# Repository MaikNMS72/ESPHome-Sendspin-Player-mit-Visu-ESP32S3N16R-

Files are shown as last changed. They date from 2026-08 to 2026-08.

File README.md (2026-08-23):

# Sendspin Gartenhaus ESPHome Player

ESPHome-Konfiguration fuer einen ESP32-S3 Player mit Sendspin,
I2S-Audio, ILI9341-Display, WS2812 Sound-to-Light und lokaler Bedienung ueber
Drehencoder und Tasten.

Der aktuelle stabile Stand ist:

`versions/sendspin-media-gartenhaus_2026-08-23_subpixel-vu-default150-nodebug.yaml`

Die aktive Datei zum Flashen ist:

`sendspin_gartenhaus_player.yaml`

## Funktionen

- Sendspin Medienplayer fuer Home Assistant
- lokaler `speaker_source` Player fuer Audioausgabe ueber I2S-Verstaerker
- Album-Art auf dem TFT-Display
- Titel, Interpret und Album als Laufschrift
- Fortschrittsbalken mit Laufzeit und Gesamtdauer
- Power-Schalter fuer Home Assistant und lokale OK-Langdruck-Bedienung
- WS2812 Sound-to-Light als analog wirkender VU-Ring
- Helligkeit und Empfindlichkeit in Home Assistant einstellbar
- Standard-Empfindlichkeit: 150%
- oberer Empfindlichkeitsbereich wird intern sanfter skaliert, damit 250% nicht sofort voll uebersteuert
- Rotary Encoder fuer Lautstaerke
- lokale Tasten fuer Tracksteuerung

## Hardware

- Board: ESP32-S3 DevKitC-1
- Flash: 16 MB
- PSRAM: Octal, 80 MHz
- Audio: zwei externe I2S-Mono-Verstaerker fuer Stereo
- Display: ILI9341 ueber SPI
- LED: WS2812 an GPIO14
- LED-Anzahl in ESPHome: 16
- Aufbau: zwei 16er-LED-Ringe parallel, deshalb wird nur ein 16er-Ring angesteuert

Details stehen in [docs/PINOUT.md](docs/PINOUT.md).
Die Bauteilliste steht in [docs/BOM.md](docs/BOM.md).

## Audio-Verstaerker

Fuer Stereo werden zwei I2S-Mono-Verstaerker verwendet. Beide Module bekommen
die I2S-Signale parallel vom ESP32-S3:

- BCLK: `GPIO7`
- LRCLK / WS: `GPIO5`
- DIN: `GPIO6`

Am linken Modul wird die L/R- beziehungsweise Channel-Select-Bruecke auf links
gesetzt, am rechten Modul auf rechts. Jeder Verstaerker treibt genau einen
Lautsprecher.

## Bilder und Demo

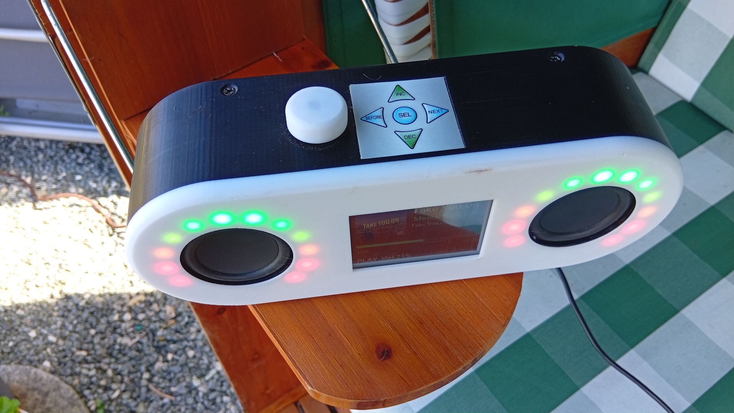
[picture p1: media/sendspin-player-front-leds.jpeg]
Sendspin Player Front mit LEDs


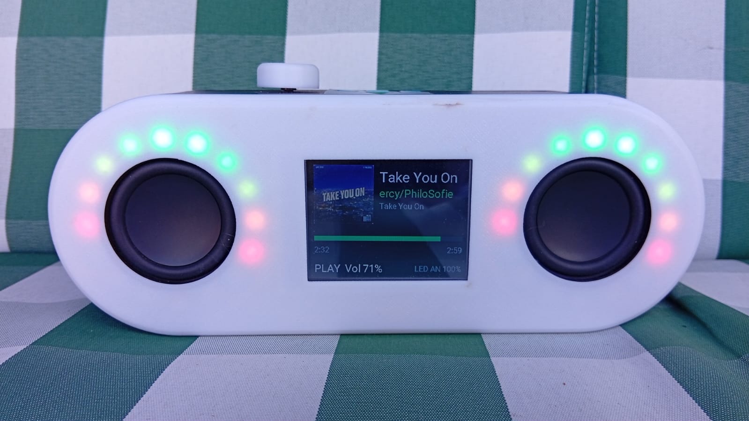
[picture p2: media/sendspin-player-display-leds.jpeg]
Sendspin Player Display und LED-Ringe


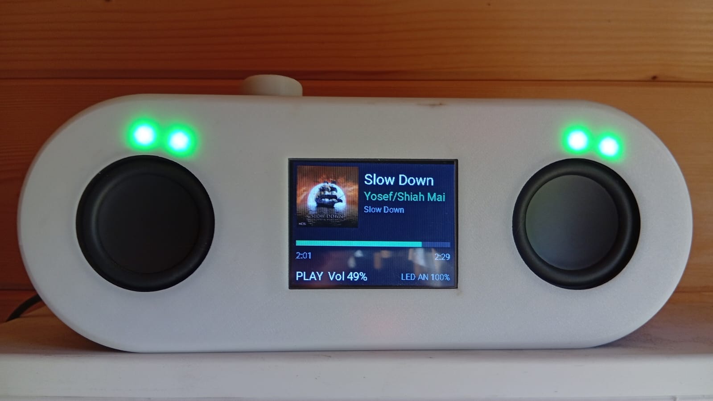
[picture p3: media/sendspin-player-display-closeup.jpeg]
Sendspin Player Display Nahaufnahme


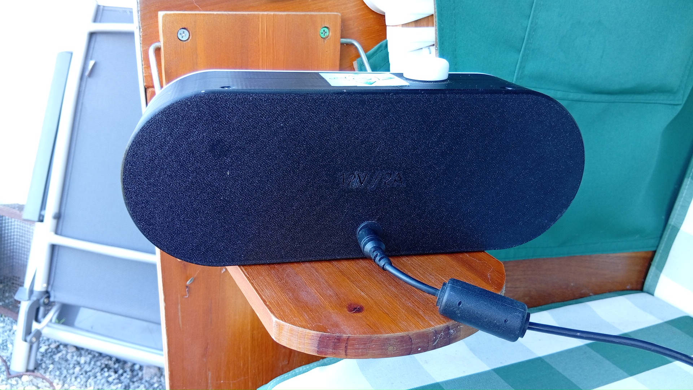
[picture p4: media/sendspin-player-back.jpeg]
Sendspin Player Rueckseite


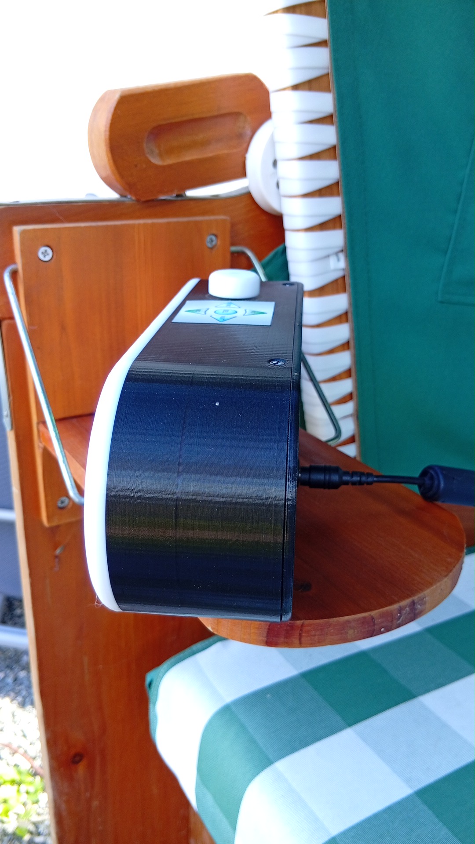
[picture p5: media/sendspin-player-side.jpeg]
Sendspin Player Seitenansicht


Video-Demo:
[YouTube: Sendspin Player Visualizer Demo](https://youtu.be/OSCCFwxxo4M)

Lokale Videodatei:
[sendspin-player-visualizer-demo.mp4](media/sendspin-player-visualizer-demo.mp4)

## 3D-Druckdaten

Die Gehaeusedaten liegen im Ordner [3d-print](3d-print/):

- `gehaeuse-esp32s3n16r8-lcd-encoder-button-body-fillet.3mf`
- `deckel-fillet001.3mf`
- `encoder-knopf-body-fillet.3mf`

Die Dateien sind im 3MF-Format abgelegt und fuer das Gehaeuse mit ESP32-S3,
LCD, Encoder und Tasten gedacht.

Vorschau:

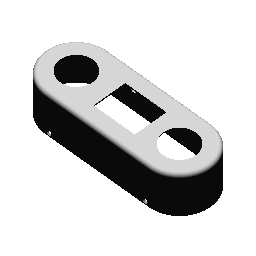
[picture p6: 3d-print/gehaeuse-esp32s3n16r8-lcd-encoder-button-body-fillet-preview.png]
Gehaeuse Vorschau

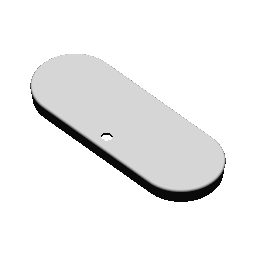
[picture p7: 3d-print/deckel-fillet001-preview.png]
Deckel Vorschau

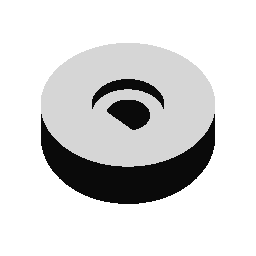
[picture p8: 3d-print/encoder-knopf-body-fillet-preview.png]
Encoder-Knopf Vorschau


## Home Assistant Entitaeten

Wichtige Entitaeten:

- `media_player.sendspin_gartenhaus_sendspin_gruppe`
- `media_player.sendspin_gartenhaus_player`
- `switch.sendspin_gartenhaus_player_power`
- `switch.sendspin_gartenhaus_sound_to_light`
- `number.sendspin_gartenhaus_sound_to_light_helligkeit`
- `number.sendspin_gartenhaus_sound_to_light_empfindlichkeit`
- `light.sendspin_gartenhaus_ws2812_leds`
- `light.sendspin_gartenhaus_display_backlight`

Der Power-Schalter schaltet lokal Display, LEDs und Verstaerker ab. Die
Media-Player `turn_on`/`turn_off` Aktionen sind mit diesem Power-Schalter
gekoppelt, damit Home Assistant, Mushroom Card und Voice Assistant den Player
ein- und ausschalten koennen.

## Bedienung

| Bedienelement | Funktion |
| --- | --- |
| Encoder drehen | Lautstaerke |
| OK kurz | Play/Pause |
| OK lang ca. 1,2 s | Player Power Ein/Aus |
| Next | Naechster Track |
| Previous | Vorheriger Track |
| INC | Vorheriger Track |
| DEC | Naechster Track |

## Sound-to-Light

Der LED-Effekt nutzt die Audiodaten aus der Sendspin-Audioquelle:

- RMS-Pegel ueber `get_audio_level()`
- Peak-Impuls ueber `consume_audio_peak()`
- LED-Update alle 35 ms
- subpixelartige Teilhelligkeit fuer weichere Uebergaenge
- VU-Anzeige von unten nach oben, symmetrisch ueber den Ring

Die Diagnoseausgabe `vu_debug` wurde im aktuellen Stand entfernt, damit der
Live-Log ruhig bleibt und keine unnoetige Last erzeugt.

## Installation

1. ESPHome 2026.8.0 oder neuer verwenden.
2. Dieses Projekt in den ESPHome-Konfigurationsordner kopieren.
3. `secrets.example.yaml` als Vorlage fuer `secrets.yaml` verwenden.
4. WLAN-Daten in `secrets.yaml` eintragen.
5. In ESPHome kompilieren und per OTA oder USB flashen.

Beispiel:

```bash
esphome compile sendspin_gartenhaus_player.yaml
esphome upload sendspin_gartenhaus_player.yaml --device sendspin-gartenhaus.local
```

## Projektstruktur

```text
sendspin_gartenhaus_player.yaml
components/
  sendspin/
  speaker_source/
3d-print/
docs/
  PINOUT.md
versions/
  README.md
  sendspin-media-gartenhaus_2026-08-23_subpixel-vu-default150-nodebug.yaml
secrets.example.yaml
```

Die Ordner `components/sendspin` und `components/speaker_source` gehoeren zum
Projekt, weil die YAML sie als lokale `external_components` nutzt.

## Hinweise

- `secrets.yaml` darf nicht nach GitHub hochgeladen werden.
- `.esphome/` enthaelt Build-Dateien und gehoert ebenfalls nicht ins Repository.
- GPIO19 wird fuer die OK-Taste genutzt. ESPHome warnt, dass GPIO19 mit
  USB-Serial-JTAG kollidieren kann. In diesem Aufbau wurde diese Warnung beim
  Kompilieren akzeptiert.

## Letzter getesteter Stand

- ESPHome: 2026.8.0
- Build: erfolgreich
- OTA-Flash: erfolgreich
- Stand: 2026-08-23, `subpixel-vu-default150-nodebug`

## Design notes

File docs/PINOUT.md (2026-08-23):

# Pinout

Pinout fuer den Sendspin Gartenhaus ESPHome Player.

## ESP32-S3

| Funktion | GPIO | Hinweis |
| --- | ---: | --- |
| Display Backlight PWM | GPIO15 | `display_backlight_pwm` |
| WS2812 Daten | GPIO14 | 16 LEDs in ESPHome, zwei 16er-Ringe parallel |
| Verstaerker Enable | GPIO21 | `amplifier_enable` |
| Rotary Encoder A | GPIO1 | Pullup aktiv |
| Rotary Encoder B | GPIO2 | Pullup aktiv |
| Taste Next | GPIO17 | invertiert, Pullup |
| Taste Previous | GPIO16 | invertiert, Pullup |
| Taste INC | GPIO4 | invertiert, Pullup |
| Taste DEC | GPIO18 | invertiert, Pullup |
| Taste OK | GPIO19 | invertiert, Pullup, Kurz/Langdruck |
| Encoder-Taster | GPIO35 | invertiert, Pullup |

## I2S Audio

| Signal | GPIO | Hinweis |
| --- | ---: | --- |
| BCLK | GPIO7 | I2S Bit Clock, parallel an beide Verstaerker |
| LRCLK / WS | GPIO5 | I2S Word Select, parallel an beide Verstaerker |
| DOUT / DIN | GPIO6 | I2S Data Out vom ESP32 zu DIN beider Verstaerker |
| AMP Enable | GPIO21 | Verstaerker-Freigabe, falls am Modul genutzt |

## I2S-Stereo mit zwei Mono-Verstaerkern

| Modul | I2S-Signale | Kanalauswahl | Lautsprecher |
| --- | --- | --- | --- |
| Linker Verstaerker | BCLK GPIO7, LRCLK GPIO5, DIN GPIO6 | L/R-Select auf links setzen | linker Lautsprecher |
| Rechter Verstaerker | BCLK GPIO7, LRCLK GPIO5, DIN GPIO6 | L/R-Select auf rechts setzen | rechter Lautsprecher |

Beide I2S-Verstaerker bekommen dieselben I2S-Signale parallel. Die Trennung in
links und rechts erfolgt ueber die L/R- beziehungsweise Channel-Select-Bruecke am
jeweiligen Modul. Beide Verstaerker muessen mit derselben Masse wie der ESP32-S3
verbunden sein.

Konfiguration:

- Stereo
- 48 kHz
- 16 Bit
- externe I2S-Verstaerker
- Buffer: 100 ms

## TFT Display ILI9341

| Signal | GPIO | Hinweis |
| --- | ---: | --- |
| SPI CLK | GPIO12 | `display_spi` |
| SPI MOSI | GPIO11 | `display_spi` |
| CS | GPIO10 | Chip Select |
| DC | GPIO13 | Data/Command |
| RESET | GPIO9 | Reset |
| Backlight | GPIO15 | PWM |

Konfiguration:

- Modell: ILI9341
- SPI: `spi2`
- SPI Mode: MODE2
- Datenrate: 20 MHz
- Rotation: 270 Grad
- Pixel Mode: 18 Bit

## LED-Ring

| Wert | Einstellung |
| --- | --- |
| LED-Typ | WS2812 |
| Datenpin | GPIO14 |
| Farbfolge | GRB |
| Anzahl in ESPHome | 16 |
| Hardware-Aufbau | 2 x 16 LEDs parallel |
| Effekt | `Sendspin Sound-to-Light` |
| Update-Intervall | 35 ms |

Die zwei Ringe sind parallel angeschlossen. Dadurch zeigen beide Ringe dasselbe
16-LED-Muster.

## Hinweise zur Verdrahtung

- Gemeinsame Masse zwischen ESP32, I2S-Verstaerkern, Display, LED-Ring und Step-Down ist erforderlich.
- WS2812-Datenleitung kurz halten oder mit Pegelanpassung betreiben, falls die LEDs mit 5 V laufen.
- Fuer WS2812 eine passende externe 5-V-Versorgung verwenden, wenn die Ringe mehr Strom ziehen.
- GPIO19 kann mit USB-Serial-JTAG kollidieren. Wenn USB-Logging oder Flashen ueber USB Probleme macht, OK-Taste testweise abklemmen oder auf einen anderen freien GPIO legen.

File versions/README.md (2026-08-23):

# Versionen

Dieser Export enthaelt nur den letzten stabil getesteten Stand.

## 2026-08-23 - subpixel-vu-default150-nodebug

Datei:

- `sendspin-media-gartenhaus_2026-08-23_subpixel-vu-default150-nodebug.yaml`

Stand:

- ESPHome 2026.8.0
- OTA erfolgreich geflasht
- Album-Art und Metadaten auf ILI9341 Display
- Titel, Interpret und Album als Laufschrift
- Sendspin Audio ueber I2S-Verstaerker
- Power-Funktion fuer Home Assistant, Mushroom Card, Voice Assistant und OK-Langdruck
- WS2812 Sound-to-Light mit subpixelartiger Teilhelligkeit
- Standard-Empfindlichkeit 150%
- Oberer Empfindlichkeitsbereich intern sanfter skaliert
- Diagnose-Logging aus dem LED-Effekt entfernt

Ruecksprung:

Diese Datei kann bei Bedarf nach `sendspin_gartenhaus_player.yaml` kopiert
und danach mit ESPHome geflasht werden.

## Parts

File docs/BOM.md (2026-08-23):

# Bill of Materials

Bill of Materials fuer den Sendspin Gartenhaus ESPHome Player.

## Bauteile

| Menge | Bauteil | Technische Daten | Verwendung | Quelle |
| ---: | --- | --- | --- | --- |
| 1 | ESP32-S3 Entwicklungsboard N16R8 | ESP32-S3, 2.4 GHz WLAN, USB-C, 44-Pin, 16 MB Flash, 8 MB PSRAM, Arduino/ESP-IDF geeignet | Hauptcontroller fuer ESPHome, Sendspin, Display, Audio, LED-Visualizer und Bedienung | [AliExpress](https://de.aliexpress.com/item/1005009962649997.html) |
| 1 | TFT Display ILI9341 SPI | 240 x 320 Pixel, SPI, ILI9341 Controller, Display-Backlight separat angesteuert | Anzeige von Album-Art, Titel, Interpret, Album, Laufzeit und Playerstatus | [AliExpress](https://de.aliexpress.com/item/1005006315533240.html) |
| 1 | Rotary Encoder mit Drucktaster | Drehencoder mit A/B-Signal und integriertem Taster | Lautstaerkeregelung per Drehung, Encoder-Taster auf GPIO35 | [AliExpress](https://de.aliexpress.com/item/1005001453647644.html) |
| 1 | 5 Key Matrix Array | 5 Tasten, einzelne GPIO-Eingaenge mit Pullup | Lokale Medientasten fuer Next, Previous, INC, DEC und OK | [AliExpress](https://de.aliexpress.com/item/1005006245093356.html) |
| 1 | DC-DC Step-Down / Buck-Wandler | Eingang 12 V, Ausgang auf 5,0 V einstellen | Spannungsversorgung von 12 V auf 5 V fuer ESP32/LED/Peripherie | [AliExpress](https://de.aliexpress.com/item/1005009690612836.html) |
| 1 | Steckernetzteil | 12 V DC, 2 A | Hauptversorgung fuer den Player | vom Benutzer angegeben |
| 2 | I2S-Mono-Verstaerker | I2S-Eingang, L/R-Kanalauswahl am Modul, Betrieb an 5 V pruefen | Stereo-Verstaerkung mit je einem Modul fuer links und rechts | [AliExpress](https://de.aliexpress.com/item/1005007003802663.html) |
| 2 | WS2812 LED-Ring 16 LEDs | adressierbarer RGB-LED-Ring, 16 LEDs, GRB-Farbfolge in ESPHome | Sound-to-Light / VU-Visualizer | [AliExpress](https://de.aliexpress.com/item/1005006140650184.html) |
| 2 | Lautsprecher | Impedanz und Leistung am gelieferten Modell pruefen | Stereo-Audioausgabe des Players | [AliExpress](https://de.aliexpress.com/item/1005007733110506.html) |

## Controller

| Merkmal | Wert |
| --- | --- |
| Modul | ESP32-S3 Entwicklungsboard |
| Variante | N16R8 |
| Flash | 16 MB |
| PSRAM | 8 MB |
| USB | Typ-C |
| Pinleiste | 44-Pin |
| Funk | 2.4 GHz WLAN |
| Framework | ESP-IDF ueber ESPHome |

Die YAML verwendet `esp32-s3-devkitc-1`, `ESP32S3`, 16 MB Flash und Octal-PSRAM
mit 80 MHz.

## Encoder-Anschluss

| Encoder-Signal | ESP32-S3 GPIO | Hinweis |
| --- | ---: | --- |
| A / CLK | GPIO1 | Rotary Encoder Eingang, Pullup aktiv |
| B / DT | GPIO2 | Rotary Encoder Eingang, Pullup aktiv |
| SW / Encoder Button | GPIO35 | Drucktaster, invertiert, Pullup aktiv |
| VCC | 3.3 V | Je nach Encoder-Modul pruefen |
| GND | GND | Gemeinsame Masse |

Der Encoder steuert in der aktuellen YAML die Lautstaerke. Der integrierte
Drucktaster liegt auf GPIO35 und ist getrennt von der OK-Taste des 5-Key-Arrays.

## 5-Key-Array-Anschluss

| Taste | ESP32-S3 GPIO | Funktion in der YAML |
| --- | ---: | --- |
| Next | GPIO17 | Naechster Track |
| Previous | GPIO16 | Vorheriger Track |
| INC | GPIO4 | Vorheriger Track |
| DEC | GPIO18 | Naechster Track |
| OK | GPIO19 | Play/Pause, langer Druck fuer Player Power Ein/Aus |
| Common / GND | GND | Gemeinsame Masse |

Die Tasten sind in ESPHome als invertierte GPIO-Eingaenge mit internem Pullup
konfiguriert. Beim Tastendruck wird der jeweilige Eingang gegen GND gezogen.

## Stromversorgung

| Bauteil | Anschluss | Hinweis |
| --- | --- | --- |
| Steckernetzteil | 12 V DC / 2 A | Eingang fuer das Geraet |
| Step-Down-Wandler Eingang | 12 V und GND | Vom Steckernetzteil |
| Step-Down-Wandler Ausgang | 5,0 V und GND | Versorgung fuer 5-V-Schiene |
| ESP32-S3 | 5 V/VIN und GND | Vom Step-Down-Ausgang, je nach Board-Beschriftung |
| WS2812 LED-Ringe | 5 V und GND | Externe 5-V-Schiene empfohlen |
| I2S-Verstaerker | 5 V und GND | Je nach Modul-Beschriftung anschliessen |

Vor dem Anschluss an ESP32, Display oder LEDs den Ausgang des Step-Down-Wandlers
mit einem Multimeter auf 5,0 V einstellen. Alle GND-Leitungen muessen verbunden
sein, damit Audio, Display, LED-Daten und Tasten sauber funktionieren.

## LED-Ringe

| LED-Signal | ESP32-S3 / Versorgung | Hinweis |
| --- | --- | --- |
| DIN | GPIO14 | Datenleitung fuer WS2812 |
| 5 V | 5-V-Schiene vom Step-Down | Externe 5-V-Versorgung empfohlen |
| GND | GND | Gemeinsame Masse mit ESP32 |

Verwendet werden zwei 16er LED-Ringe. Beide Ringe sind parallel angeschlossen,
deshalb ist in ESPHome `num_leds: 16` konfiguriert. Beide Ringe zeigen dadurch
das gleiche 16-LED-Muster.

## Audio-Ausgang

| Bauteil | Anschluss | Hinweis |
| --- | --- | --- |
| I2S-Verstaerker links | BCLK GPIO7, LRCLK GPIO5, DIN GPIO6 | L/R-Select am Modul auf linken Kanal setzen |
| I2S-Verstaerker rechts | BCLK GPIO7, LRCLK GPIO5, DIN GPIO6 | L/R-Select am Modul auf rechten Kanal setzen |
| I2S-Verstaerker links | 5 V und GND | Versorgung von der 5-V-Schiene |
| I2S-Verstaerker rechts | 5 V und GND | Versorgung von der 5-V-Schiene |
| Lautsprecher links | Ausgang des linken Verstaerkers | Polung beachten |
| Lautsprecher rechts | Ausgang des rechten Verstaerkers | Polung beachten |

Die Lautsprecher werden nicht direkt vom ESP32-S3 angetrieben, sondern ueber den
I2S-Verstaerker. Fuer Stereo werden zwei gleiche I2S-Mono-Verstaerker verwendet.
BCLK, LRCLK/WS und DIN werden parallel auf beide Module gefuehrt. Das linke
Modul wird per L/R-Select auf links gesetzt, das rechte Modul per L/R-Select auf
rechts. Impedanz und maximale Leistung der Lautsprecher muessen zum verwendeten
Verstaerker-Modul passen.

## Display-Anschluss

| Display-Signal | ESP32-S3 GPIO | Hinweis |
| --- | ---: | --- |
| CLK / SCK | GPIO12 | SPI Clock |
| MOSI / SDI | GPIO11 | SPI Data |
| CS | GPIO10 | Chip Select |
| DC | GPIO13 | Data/Command |
| RESET | GPIO9 | Display Reset |
| LED / BL | GPIO15 | Backlight per PWM |
| VCC | 3.3 V | Je nach Modul pruefen |
| GND | GND | Gemeinsame Masse |

## Hinweise

- Touch-Pins des Display-Moduls werden in der aktuellen ESPHome-Konfiguration nicht genutzt.
- In ESPHome ist das Display als `ili9xxx` mit Modell `ILI9341`, Rotation `270`, SPI Mode `MODE2` und 20 MHz Datenrate konfiguriert.
- Die genaue Display-Groesse bitte am gelieferten Modul gegenpruefen, da AliExpress-Angebote haeufig mehrere Varianten unter einem Artikel fuehren.

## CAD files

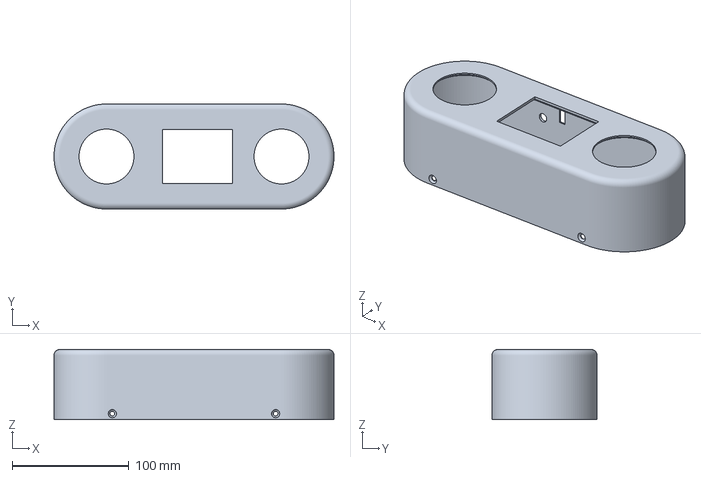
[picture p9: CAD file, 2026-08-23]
3d-print/gehaeuse-esp32s3n16r8-lcd-encoder-button-body-fillet.3mf
240.0 x 90.0 x 60.0 mm

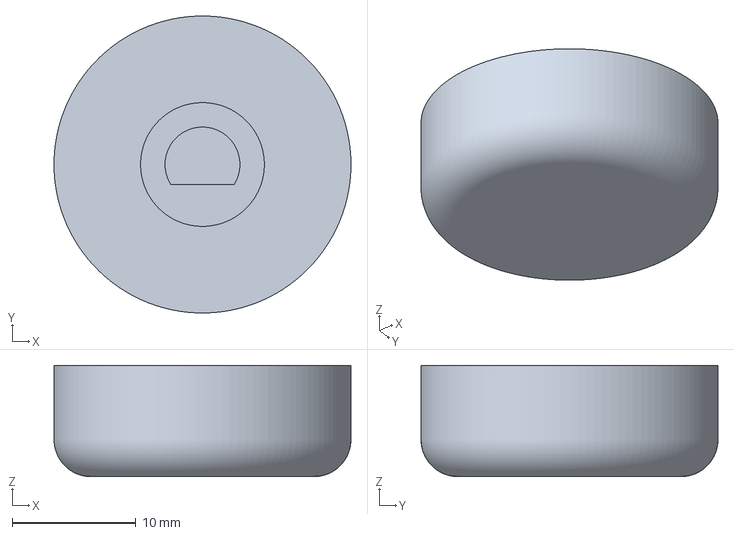
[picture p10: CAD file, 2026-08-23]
3d-print/encoder-knopf-body-fillet.3mf
24.0 x 24.0 x 9.00 mm

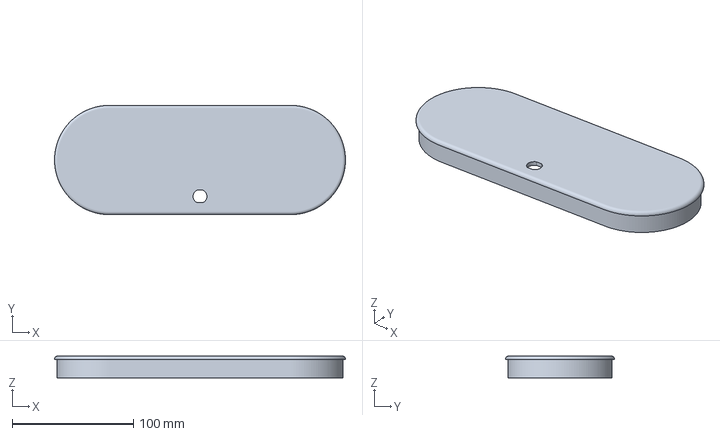
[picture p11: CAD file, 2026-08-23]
3d-print/deckel-fillet001.3mf
240.0 x 90.0 x 18.0 mm

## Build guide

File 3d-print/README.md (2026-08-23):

# 3D-Druckdaten

Dieser Ordner enthaelt die 3MF-Dateien fuer das Gehaeuse des Sendspin
Gartenhaus ESPHome Players.

## Dateien

| Datei | Beschreibung |
| --- | --- |
| `gehaeuse-esp32s3n16r8-lcd-encoder-button-body-fillet.3mf` | Hauptgehaeuse fuer ESP32-S3 N16R8, LCD, Encoder und Tasten |
| `deckel-fillet001.3mf` | Deckel fuer das Gehaeuse |
| `encoder-knopf-body-fillet.3mf` | Drehknopf fuer den Encoder |

## Vorschau

### Gehaeuse

Gehaeuse Vorschau

### Deckel

Deckel Vorschau

### Encoder-Knopf

Encoder-Knopf Vorschau

## Hinweise

- Format: 3MF
- Die Dateien wurden mit GitHub-freundlichen Namen ohne Leerzeichen und Umlaute abgelegt.
- Vor dem Druck bitte Ausrichtung, Stuetzstrukturen und Materialeinstellungen im Slicer pruefen.

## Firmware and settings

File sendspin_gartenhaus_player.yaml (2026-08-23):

substitutions:
  # Eindeutiger ESPHome-Name. Dieser Name bestimmt auch die OTA/mDNS-Adresse.
  name: sendspin-gartenhaus
  # Anzeigename fuer Home Assistant Entitaeten.
  friendly_name: Sendspin Gartenhaus
  # Audio-Tasks laufen mit PSRAM-Stack, damit der interne RAM fuer Echtzeit-Audio frei bleibt.
  task_stack_in_psram: "true"

esphome:
  name: ${name}
  friendly_name: ${friendly_name}
  min_version: 2026.8.0

external_components:
  # Lokale Komponenten aus diesem Repository:
  # - sendspin: Protokoll, Album-Art, Metadaten und Audioquelle
  # - speaker_source: lokaler Media-Player, der die Sendspin-Audioquelle ausgibt
  - source:
      type: local
      path: components
    components:
      - sendspin
      - speaker_source

esp32:
  # ESP32-S3 N16R8 Board mit 16 MB Flash und Octal-PSRAM.
  board: esp32-s3-devkitc-1
  variant: ESP32S3
  flash_size: 16MB
  framework:
    type: esp-idf
    version: recommended
    sdkconfig_options:
      CONFIG_ESP32S3_DATA_CACHE_64KB: "y"
      CONFIG_ESP32S3_DATA_CACHE_LINE_64B: "y"
      CONFIG_SPIRAM_RODATA: "y"
      CONFIG_SPIRAM_FETCH_INSTRUCTIONS: "y"
      CONFIG_MBEDTLS_EXTERNAL_MEM_ALLOC: "y"

psram:
  # PSRAM wird fuer groessere Audio-/Netzwerkpuffer und Task-Stacks genutzt.
  mode: octal
  speed: 80MHz

logger:
  level: INFO

api:

ota:
  platform: esphome

wifi:
  # WLAN-Zugangsdaten kommen aus secrets.yaml und werden nicht ins GitHub-Repo gelegt.
  ssid: !secret wifi_ssid
  password: !secret wifi_password
  ap:
    ssid: "${friendly_name} Fallback"
    password: "sendspin"

captive_portal:

mdns:

globals:
  # Laufvariablen fuer Laufschrift und VU-Visualizer. Sie werden nach Neustart nicht wiederhergestellt.
  - id: stl_phase
    type: uint32_t
    restore_value: false
    initial_value: "0"
  - id: marquee_tick
    type: uint32_t
    restore_value: false
    initial_value: "0"
  - id: vu_level
    type: float
    restore_value: false
    initial_value: "0.0"
  - id: vu_fast_env
    type: float
    restore_value: false
    initial_value: "0.0"
  - id: vu_slow_env
    type: float
    restore_value: false
    initial_value: "0.08"
  - id: vu_beat_env
    type: float
    restore_value: false
    initial_value: "0.0"
  - id: vu_active_since_ms
    type: uint32_t
    restore_value: false
    initial_value: "0"
  - id: ok_long_press_handled
    type: bool
    restore_value: false
    initial_value: "false"

script:
  # Zentrale Power-On-Aktion: Verstaerker und Display einschalten, VU-Zustand zuruecksetzen.
  - id: player_power_on_actions
    mode: restart
    then:
      - switch.turn_on: amplifier_enable
      - light.turn_on:
          id: display_backlight
          brightness: 100%
      - lambda: |-
          // Visualizer nach Power-On sauber starten.
          id(vu_level) = 0.0f;
          id(vu_fast_env) = 0.0f;
          id(vu_slow_env) = 0.08f;
          id(vu_beat_env) = 0.0f;
          id(vu_active_since_ms) = 0;
      - if:
          condition:
            and:
              - switch.is_on: sound_to_light_enabled
              - media_player.is_playing: sendspin_player
          then:
            - light.turn_on:
                id: ws2812_leds
                effect: "Sendspin Sound-to-Light"
                brightness: !lambda "return id(sound_to_light_level).state / 100.0f;"

  - id: player_power_off_actions
    # Power-Off stoppt die Wiedergabe und schaltet lokale Verbraucher ab.
    mode: restart
    then:
      - media_player.stop: sendspin_group_player
      - light.turn_off: ws2812_leds
      - light.turn_off: display_backlight
      - switch.turn_off: amplifier_enable
      - lambda: |-
          // VU-Zustand loeschen, damit beim naechsten Start keine alten Pegel sichtbar sind.
          id(vu_level) = 0.0f;
          id(vu_fast_env) = 0.0f;
          id(vu_slow_env) = 0.08f;
          id(vu_beat_env) = 0.0f;
          id(vu_active_since_ms) = 0;

  - id: next_track_guarded
    # Guard gegen sehr schnelle Doppeltrigger der Tasten.
    mode: single
    then:
      - media_player.next: sendspin_group_player
      - delay: 900ms

  - id: previous_track_guarded
    mode: single
    then:
      - media_player.previous: sendspin_group_player
      - delay: 900ms

  - id: volume_up_guarded
    # mode: restart macht schnelle Encoder-Drehungen direkter.
    mode: restart
    then:
      - media_player.volume_up: sendspin_group_player

  - id: volume_down_guarded
    mode: restart
    then:
      - media_player.volume_down: sendspin_group_player
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

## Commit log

2026-08-23 Add 3D print enclosure files
    [deckel-fillet001.3mf, encoder-knopf-body-fillet.3mf, gehaeuse-esp32s3n16r8-lcd-encoder-button-body-fillet.3mf]
2026-08-23 Add BOM and correct button pinout
    [sendspin-media-gartenhaus_2026-08-23_subpixel-vu-default150-nodebug.yaml, sendspin_gartenhaus_player.yaml]
2026-08-23 Document I2S stereo amplifier wiring
2026-08-23 Add 3D print preview images
2026-08-23 Add ESP32 board source link to BOM
